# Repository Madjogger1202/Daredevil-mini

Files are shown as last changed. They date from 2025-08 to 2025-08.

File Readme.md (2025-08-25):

# Daredevil-mini

> USB MEMS microphone module with four selectable sensors on one board.  
> **Sensors:** INMP441 • MP34DT01 • SPH0645LM4 • MP23DB01.  
> Each sensor wired individually to **RP2040** core.  
> Form factor: **USB stick** (direct plug-in).  

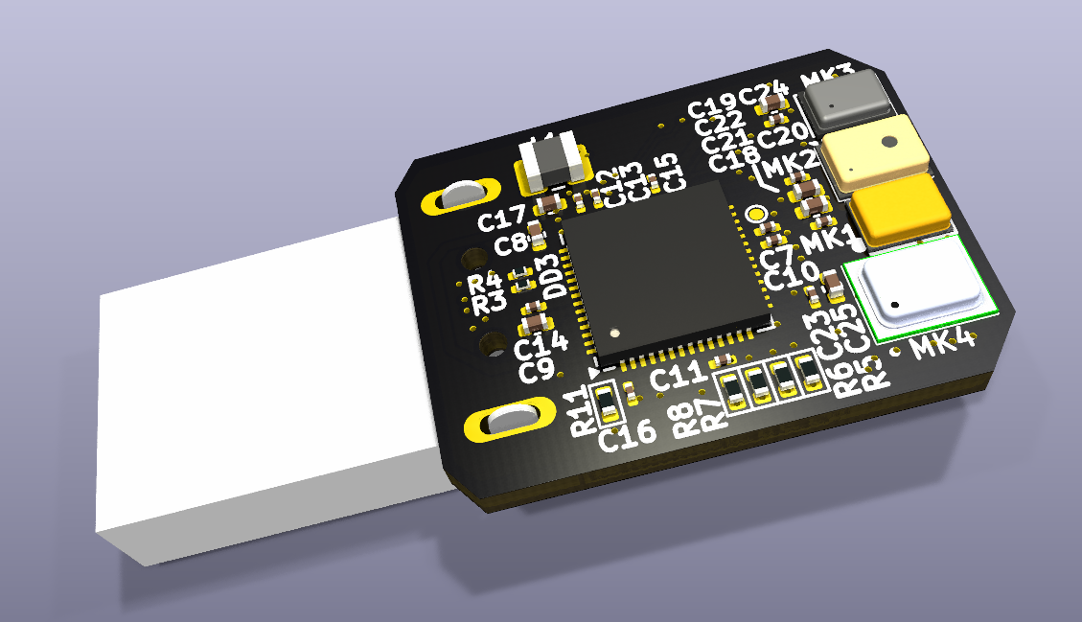
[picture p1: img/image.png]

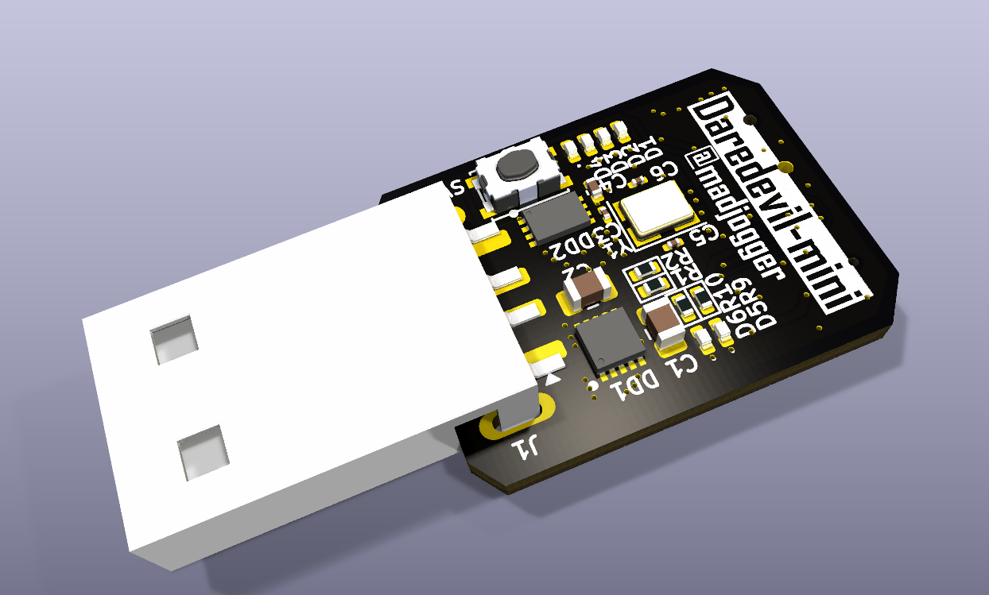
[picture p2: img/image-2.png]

---

## What’s on the board
- **Four MEMS microphones** for direct comparison:
  - INMP441  
  - MP34DT01  
  - SPH0645LM4  
  - MP23DB01
- All connected separately to **RP2040**  
  *(see schematic for detailed pinout)*
- **Two groups of LEDs**:
  - 2× status LEDs (power / activity)  
  - 4× level LEDs (visualize audio from active sensor)
- **BOOT button** for easy programming (UF2 bootloader compatible)
- Component layout matches **Raspberry Pi Pico** (same footprints / values for cost-reduction & rework flexibility)

---

## Power & Form Factor
- Powered directly from **USB-A plug**  
- Compact **flash-drive-style** PCB — just insert into USB port  
- No external power required

---

## Use Case
- Quick **A/B/C/D comparison** of MEMS microphones  
- Evaluate noise, sensitivity, frequency response, clipping  
- Decide on best sensor for a given project (voice, audio capture, beamforming, etc.)

---

## Quick Use
1. Plug **Daredevil-mini** into USB port.  
2. Hold **BOOT** and connect to enter RP2040 bootloader.  
3. Flash your firmware (UF2 or via SWD if needed).  
4. Select and test microphones, use LED bar as quick visual feedback.  
5. Log / stream audio over USB or I²S as defined in firmware.

---

## Notes
- Do not use multiple sensors at the same time (shared core, for comparison only).  
- Pin mapping for each microphone: **see schematic**.  
- Board re-buildable using **Pi Pico BOM** (same package sizes).  

---

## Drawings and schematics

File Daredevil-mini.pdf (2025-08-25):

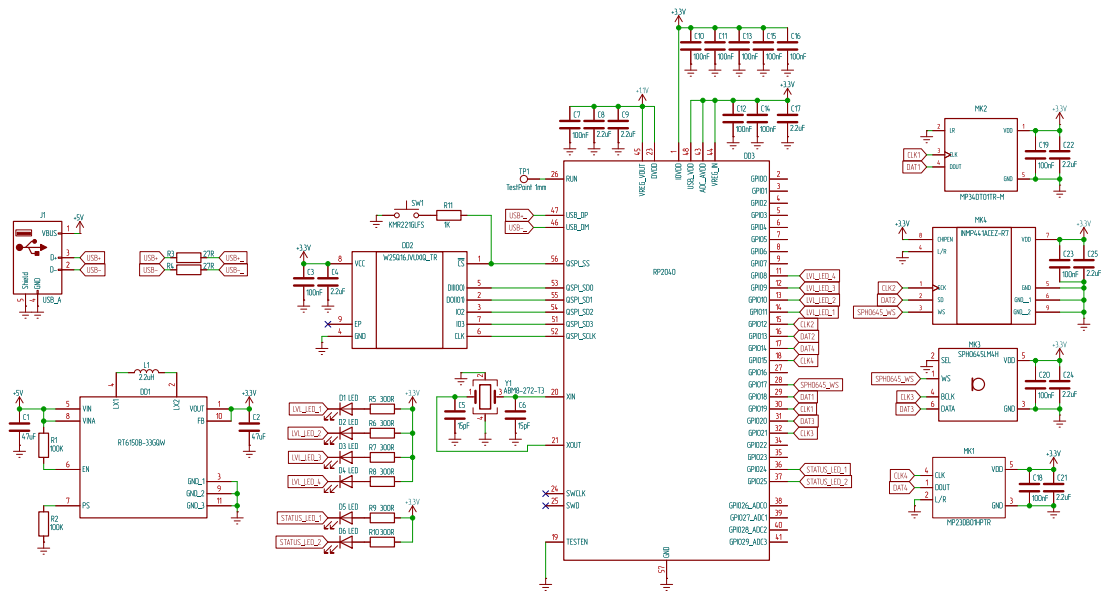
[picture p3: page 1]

þÿ@>2.
þÿ".:>=B@.

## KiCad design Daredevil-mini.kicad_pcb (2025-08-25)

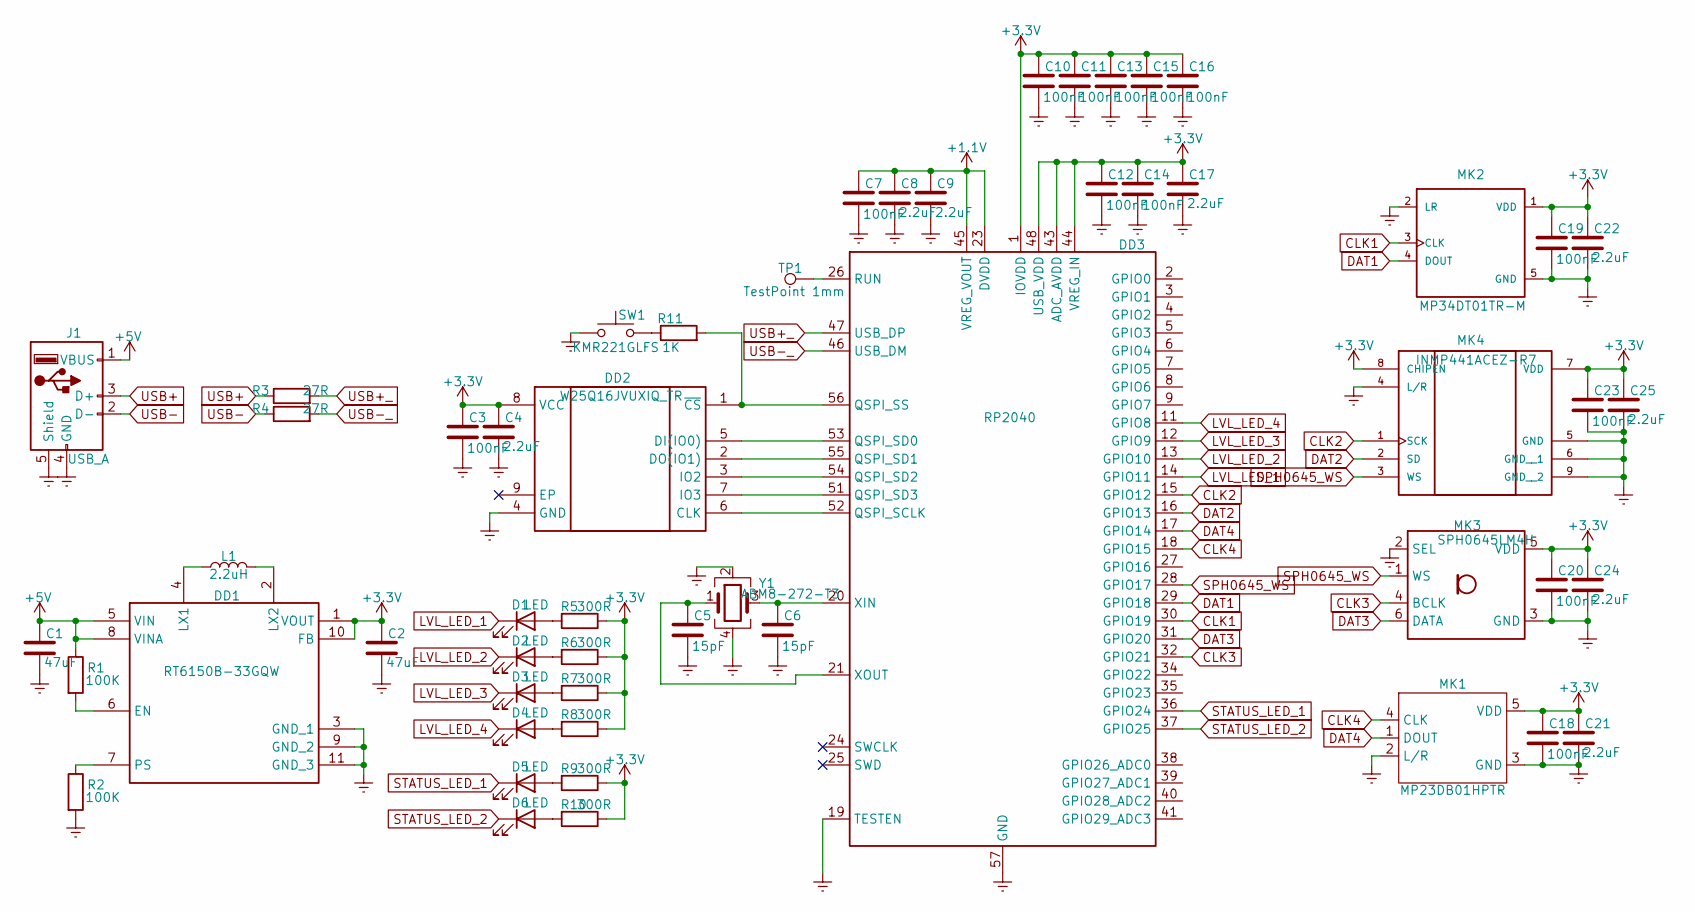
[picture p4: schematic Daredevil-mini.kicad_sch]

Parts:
C1, C2: 47uF; C_0805_2012Metric
C3, C7, C10, C11, C12, C13, C14, C15, C16, C18, C19, C20, C23: 100nF; C_0201_0603Metric
C4, C8, C9, C17, C21, C22, C24, C25: 2.2uF; C_0402_1005Metric
C5, C6: 15pF; C_0201_0603Metric
D1, D2, D3, D4, D5, D6: LED; LED_0402_1005Metric
DD1: RT6150B-33GQW; Manufacturer_Part_Number RT6150B-33GQW; Mouser Part Number 835-RT6150B-33GQW
DD2: W25Q16JVUXIQ_TR; W25Q16JVUXIQ; Manufacturer_Part_Number W25Q16JVUXIQ TR; Mouser Part Number 454-W25Q16JVUXIQTR
DD3: RP2040; QFN-56-1EP_7x7mm_P0.4mm_EP3.2x3.2mm
J1: USB_A; USB_A_Connfly_DS1098_Horizontal
L1: 2.2uH; L_1008_2520Metric
MK1: MP23DB01HPTR; Manufacturer Part MP23DB01HPTR; LCSC Part Name MP23DB01HPTR
MK2: MP34DT01TR-M; MP34DT01; MPN MP34DT01TR-M
MK3: SPH0645LM4H; Knowles_SPH0645LM4H-6_3.5x2.65mm
MK4: INMP441ACEZ-R7; INMP441; PARTREV 1.1
R1, R2: 100K; R_0402_1005Metric
R3, R4: 27R; R_0201_0603Metric
R5, R6, R7, R8, R9, R10: 300R; R_0402_1005Metric
R11: 1K; R_0402_1005Metric
SW1: KMR221GLFS; SW_SPST_PTS810
TP1: TestPoint 1mm; TestPoint_Pad_D1.0mm
Y1: ABM8-272-T3; Crystal_SMD_3225-4Pin_3.2x2.5mm

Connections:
+1.1V: C7.1, C8.1, C9.1, DD3.23 (DVDD), DD3.45 (VREG_VOUT), DD3.50 (DVDD)
+3.3V: C2.1, C3.1, C4.1, C10.1, C11.1, C12.1, C13.1, C14.1, C15.1, C16.1, C17.1, C18.1, C19.1, C20.1, C21.1, C22.1, C23.1, C24.1, C25.1, DD1.1 (VOUT), DD1.10 (FB), DD2.8 (VCC), DD3.1 (IOVDD), DD3.10 (IOVDD), DD3.22 (IOVDD), DD3.33 (IOVDD), DD3.42 (IOVDD), DD3.43 (ADC_AVDD), DD3.44 (VREG_IN), DD3.48 (USB_VDD), DD3.49 (IOVDD), MK1.5 (VDD), MK2.1 (VDD), MK3.5 (VDD), MK4.7 (VDD), MK4.8 (CHIPEN), R5.1, R6.1, R7.1, R8.1, R9.1, R10.1
+5V: C1.1, DD1.5 (VIN), DD1.8 (VINA), J1.1 (VBUS), R1.1
CLK1: DD3.30 (GPIO19), MK2.3 (CLK)
CLK2: DD3.15 (GPIO12), MK4.1 (SCK)
CLK3: DD3.32 (GPIO21), MK3.4 (BCLK)
CLK4: DD3.18 (GPIO15), MK1.4 (CLK)
DAT1: DD3.29 (GPIO18), MK2.4 (DOUT)
DAT2: DD3.16 (GPIO13), MK4.2 (SD)
DAT3: DD3.31 (GPIO20), MK3.6 (DATA)
DAT4: DD3.17 (GPIO14), MK1.1 (DOUT)
Earth: C1.2, C2.2, C3.2, C4.2, C5.2, C6.2, C7.2, C8.2, C9.2, C10.2, C11.2, C12.2, C13.2, C14.2, C15.2, C16.2, C17.2, C18.2, C19.2, C20.2, C21.2, C22.2, C23.2, C24.2, C25.2, DD1.3 (GND_1), DD1.9 (GND_2), DD1.11 (GND_3), DD2.4 (GND), DD3.19 (TESTEN), DD3.57 (GND), J1.4 (GND), J1.5 (Shield), MK1.2 (L/R), MK1.3 (GND), MK2.2 (LR), MK2.5 (GND), MK3.2 (SEL), MK3.3 (GND), MK4.4 (L/R), MK4.5 (GND), MK4.6 (GND__1), MK4.9 (GND__2), R2.2, SW1.1, Y1.2, Y1.4
LVL_LED_1: D1.1 (K), DD3.14 (GPIO11)
LVL_LED_2: D2.1 (K), DD3.13 (GPIO10)
LVL_LED_3: D3.1 (K), DD3.12 (GPIO9)
LVL_LED_4: D4.1 (K), DD3.11 (GPIO8)
unnamed: D1.2 (A), R5.2
unnamed: D2.2 (A), R6.2
unnamed: D3.2 (A), R7.2
unnamed: D4.2 (A), R8.2
unnamed: D5.2 (A), R9.2
unnamed: D6.2 (A), R10.2
unnamed: DD1.6 (EN), R1.2
unnamed: DD1.4 (LX1), L1.1
unnamed: DD1.2 (LX2), L1.2
unnamed: DD1.7 (PS), R2.1
unnamed: DD2.6 (CLK), DD3.52 (QSPI_SCLK)
unnamed: DD2.5 (DI(IO0)), DD3.53 (QSPI_SD0)
unnamed: DD2.2 (DO(IO1)), DD3.55 (QSPI_SD1)
unnamed: DD2.3 (IO2), DD3.54 (QSPI_SD2)
unnamed: DD2.7 (IO3), DD3.51 (QSPI_SD3)
unnamed: DD2.1 (~CS), DD3.56 (QSPI_SS), R11.2
unnamed: DD3.26 (RUN), TP1.1
unnamed: C6.1, DD3.20 (XIN), Y1.3
unnamed: C5.1, DD3.21 (XOUT), Y1.1
unnamed: R11.1, SW1.2
SPH0645_WS: DD3.28 (GPIO17), MK3.1 (WS), MK4.3 (WS)
STATUS_LED_1: D5.1 (K), DD3.36 (GPIO24)
STATUS_LED_2: D6.1 (K), DD3.37 (GPIO25)
USB+: J1.3 (D+), R3.1
USB+_: DD3.47 (USB_DP), R3.2
USB-: J1.2 (D-), R4.1
USB-_: DD3.46 (USB_DM), R4.2

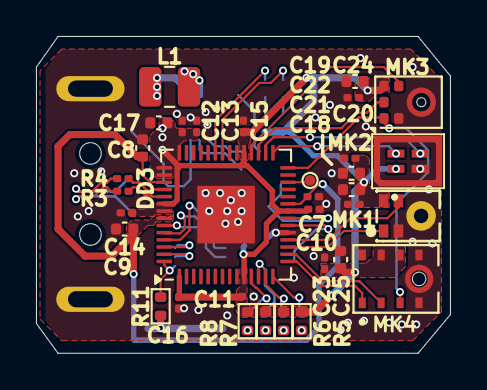
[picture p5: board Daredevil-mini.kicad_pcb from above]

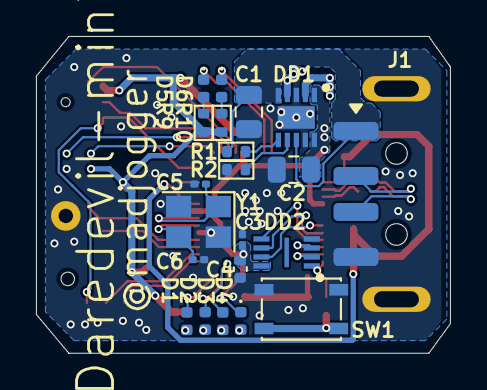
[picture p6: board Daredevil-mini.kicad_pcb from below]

Board: 2 copper layers, 23.0 x 17.6 mm, 54 parts (21 on the bottom side), 43 nets.

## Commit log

2025-08-24 Schematics done, all 3D models in places and imported all components on PCB, ready to work on PCB
    [Daredevil-mini.kicad_pcb, Daredevil-mini.kicad_sch]
2025-08-25 udp PCB
    [Daredevil-mini.kicad_pcb, Daredevil-mini.kicad_sch]
2025-08-25 rev0 ready
    [Daredevil-mini-B_Cu.gbr, Daredevil-mini-B_Mask.gbr, Daredevil-mini-B_Paste.gbr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]
